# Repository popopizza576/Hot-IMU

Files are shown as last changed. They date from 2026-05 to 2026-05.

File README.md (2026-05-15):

# What is Hot IMU?
The Hot IMU is an IMU based camera tracker that attaches to any hot or cold shoe on a camera and captures its movement. This helps to create dynamic backgrounds using that movement data for compositing green screens instead of static images, which adds a whole new realm of possibilities to what you can do in video post-production and VFX!
### <a href="https://youtu.be/kCqcRCQPGMA">Watch the video here!</a>
github
ezgif-frame-

# Why use Hot IMU?
The Hot IMU is a great alternative to current Vive-tracker-based solutions for green screen compositing. The Hot IMU does not require any base stations or setup, just put it on and click go, and it will record your motion data.

The Hot IMU is also incredibly affordable compared to the current Vive-tracker-based solutions. It's also extremely affordable, not requiring base stations, which means you can use it virtually anywhere!

# Zine Page

hot IMU

# Assembly
The Hot IMU is a compact ESP-32c3-based device, with a BNO085 IMU and OLED screen. The IMU and OLED screen mount to the PCB with breadboard pins. The battery mounts using a JST 2-pin 1.5mm connector.

### PCB



### Schematic



### BOM

I have created two separate BOMs for my project, because some parts you can't order on Digikey. 

The first BOM plugs into Digikeys' lists and allows you to order things like SMD components for your board.

The second BOM is a list of all additional components you need to buy in order to complete the project.

**You need to buy the contents of BOTH BOMs to build this project!!!**

<a href="https://github.com/popopizza576/Hot-IMU/blob/main/BOM.csv">BOM1</a><br></br>
<a href="https://github.com/popopizza576/Hot-IMU/blob/main/BOM2.csv">BOM2</a>

**PLEASE NOTE**

In addition to purchasing the parts from the BOM, you must have access to a 3D Printer to print the shell for this project.

Also, note that you need to get a quote from a PCB manufacturer of your choosing. **YOU MUST PURCHASE A PCB** The PCB is not included in either BOM.

# Usage
The Hot IMU records movement data to the SD card in CSV format. It records one frame of motion data per frame, and the framerate is specified on the OLED screen.

You can change the framerate by holding down the GO button and pressing the STOP button. The built-in framerates are 24, 30, 60, and 120. the default framerate is 24.

After you've got your CSV file of the motion data recorded, you need to create a Blender scene and find the file path. There is a blender script you need to put in the Scripting tab in Blender.

The Blender Script will parse through the motion data and create an animation of the length of the duration of the data you recorded, then it creates 1 frame of animation for every frame and maps your camera movement to the motion capture.

After you render your Blender animation, just sync up your animation and footage from your camera in your editing software of choice, and key out the background!


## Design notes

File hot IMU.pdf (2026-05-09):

## Dynamic Composites using

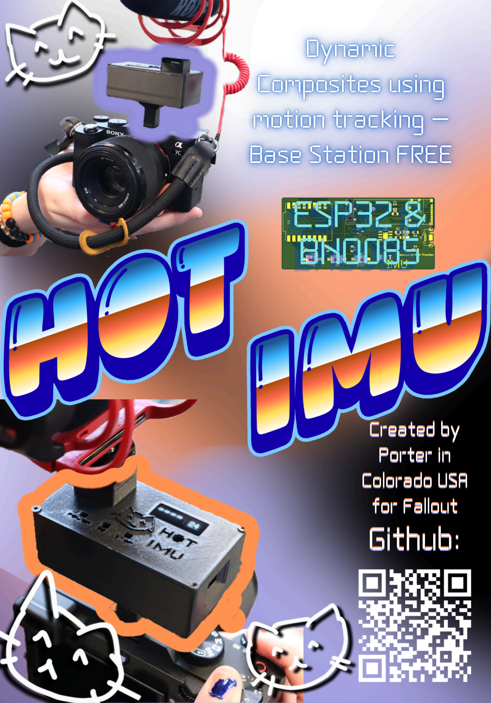
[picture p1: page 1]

## motion tracking -Base Station FREE

Created by
PPoorrtteerr i

inn
CCool

loorraaddoo UUSSAA
ffoorr FFaal

ll

loouutt

## GGiitthhuubb::

Created by
Porter in
Colorado USA
for Fallout

## Github:

# EEESSSPPP333222&&& BBBNNNOOO000888555

# ESP32 & BNO085

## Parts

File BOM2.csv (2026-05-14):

Part (Reference) | Qty | Link | Price
BNO085 | 1 | https://www.aliexpress.us/item/3256811467490032.html | $20.91
OLED 128×32 i2c | 1 | https://www.aliexpress.us/item/3256811597067737.html | $2.85
Self-tapping m2 screws | 1 | https://www.aliexpress.us/item/3256810220525698.html | $4.83
pin header (J4) | 1 | https://pmdway.com/products/single-row-smt-smd-female-header-socket-10-pack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 | $14.37
Battery (2 pin 1.5mm) | 1 | https://www.aliexpress.us/item/3256806334906334.html | $8.11

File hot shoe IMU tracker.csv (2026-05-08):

Reference | Qty | Value | DNP | Exclude from BOM | Exclude from Board | Footprint | Datasheet | MPN
BT1 | 1 | Battery |  |  |  | Connector_JST:JST_ACH_BM02B-ACHSS-GAN-ETF_1x02-1MP_P1.20mm_Vertical | ~ | B2B-ZR-SM4-TF
C1 | 1 | 0.1 |  |  |  | Capacitor_SMD:C_0402_1005Metric_Pad0.74x0.62mm_HandSolder | ~ | GRM155R71C104KA88D
C2 | 1 | 10 |  |  |  | Capacitor_SMD:C_0402_1005Metric_Pad0.74x0.62mm_HandSolder | ~ | GRM155R61A106ME11D
D1,D2 | 2 | LED |  |  |  | LED_SMD:LED_0805_2012Metric_Pad1.15x1.40mm_HandSolder | ~ | LTST-C170KRKT,LTST-C171KGKT
J1 | 1 | USB_B_Micro |  |  |  | Connector_USB:USB_Micro-AB_Molex_47590-0001 | ~ | 0475900001
J2 | 1 | Micro_SD_Card |  |  |  | Connector_Card:microSD_HC_Molex_104031-0811 | https://www.we-online.com/components/products/datasheet/693072010801.pdf | 1040310811
J3 | 1 | OLED |  |  |  | Connector_PinHeader_1.00mm:PinHeader_1x04_P1.00mm_Vertical_SMD_Pin1Left | ~ | SSM-104-L-SV-K-TR
J4 | 1 | BNO085 |  |  |  | Connector_PinHeader_1.27mm:PinHeader_1x10_P1.27mm_Vertical_SMD_Pin1Left | ~ | SSM-104-L-SV-K-TR
Q1 | 1 | 2N7002 |  |  |  | Package_TO_SOT_SMD:SOT-23 | https://www.onsemi.com/pub/Collateral/NDS7002A-D.PDF | 2N7002
R1,R2 | 2 | 1k |  |  |  | Resistor_SMD:R_0805_2012Metric_Pad1.20x1.40mm_HandSolder | ~ | CRCW08051K00FKEA
R3 | 1 | 0.4 |  |  |  | Resistor_SMD:R_0805_2012Metric_Pad1.20x1.40mm_HandSolder | ~ | RCWP0575400RGKS6
R4 | 1 | 1.2k |  |  |  | Resistor_SMD:R_0805_2012Metric_Pad1.20x1.40mm_HandSolder | ~ | CRCW08051K20FKEA
R5,R6,R7,R8 | 4 | 10k |  |  |  | Resistor_SMD:R_0805_2012Metric_Pad1.20x1.40mm_HandSolder | ~ | CRCW080510K0FKEA
SW1 | 1 | Power |  |  |  | Button_Switch_SMD:SW_DIP_SPSTx01_Slide_6.7x4.1mm_W8.61mm_P2.54mm_LowProfile | ~ | RS-282G05A3-SM RT
SW2 | 1 | Start |  |  |  | Button_Switch_SMD:SW_DIP_SPSTx01_Slide_6.7x4.1mm_W8.61mm_P2.54mm_LowProfile | ~ | RS-282G05A3-SM RT
SW3 | 1 | Stop |  |  |  | Button_Switch_SMD:SW_DIP_SPSTx01_Slide_6.7x4.1mm_W8.61mm_P2.54mm_LowProfile | ~ | RS-282G05A3-SM RT
U1 | 1 | ESP32-C3_SUPERMINI_TH |  |  |  | hot shoe:MODULE_ESP32-C3_SUPERMINI |  | 26892
U2 | 1 | TP4056-42-ESOP8 |  |  |  | Package_SO:SOIC-8-1EP_3.9x4.9mm_P1.27mm_EP2.41x3.3mm_ThermalVias | https://www.lcsc.com/datasheet/lcsc_datasheet_2410121619_TOPPOWER-Nanjing-Extension-Microelectronics-TP4056-42-ESOP8_C16581.pdf | TPB4056A20-ES1R

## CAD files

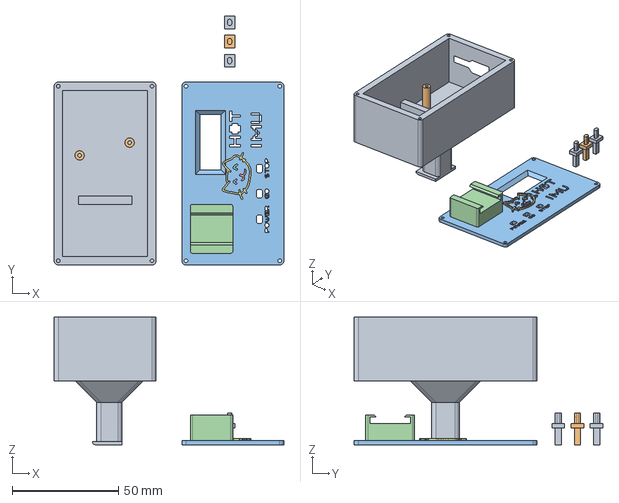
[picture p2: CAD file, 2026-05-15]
cad/body.step
108.0 x 117.0 x 60.0 mm

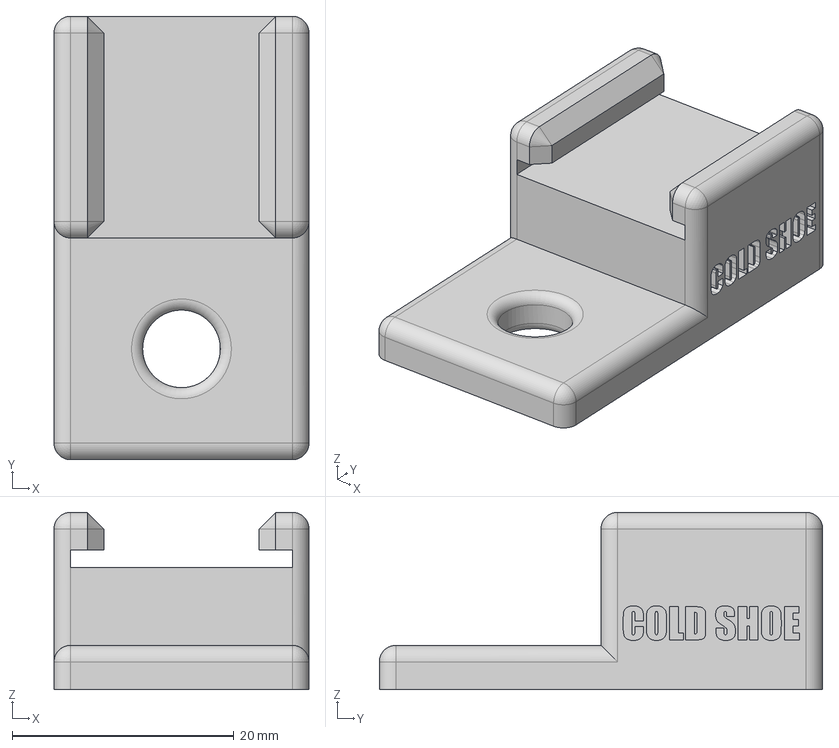
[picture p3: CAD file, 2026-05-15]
cad/m14-20 to cold shoe.step
23.0 x 40.0 x 16.0 mm

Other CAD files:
cad/body.f3d
cad/body.stl
cad/m14-20 to cold shoe.f3d
cad/m14-20 to cold shoe.stl

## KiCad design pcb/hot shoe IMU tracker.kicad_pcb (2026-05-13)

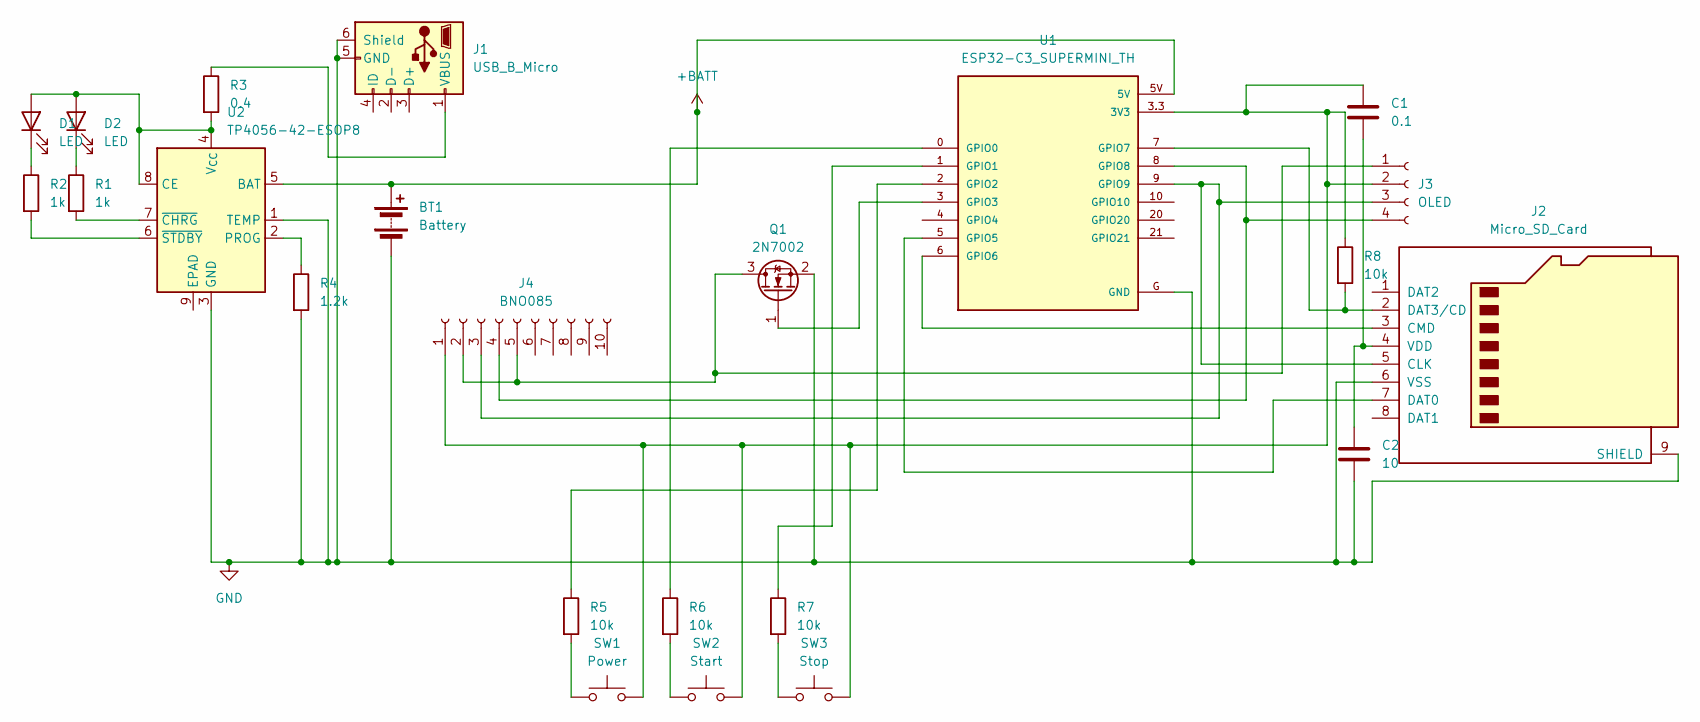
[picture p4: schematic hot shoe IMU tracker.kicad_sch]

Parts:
BT1: Battery; JST_ACH_BM02B-ACHSS-GAN-ETF_1x02-1MP_P1.20mm_Vertical; MPN B2B-ZR-SM4-TF
C1: 0.1; C_0402_1005Metric_Pad0.74x0.62mm_HandSolder; MPN GRM155R71C104KA88D
C2: 10; C_0402_1005Metric_Pad0.74x0.62mm_HandSolder; MPN GRM155R61A106ME11D
D1: LED; LED_0805_2012Metric_Pad1.15x1.40mm_HandSolder; MPN LTST-C171KGKT
D2: LED; LED_0805_2012Metric_Pad1.15x1.40mm_HandSolder; MPN LTST-C170KRKT
J1: USB_B_Micro; USB_Micro-AB_Molex_47590-0001; MPN 0475900001
J2: Micro_SD_Card; microSD_HC_Molex_104031-0811; MPN 1040310811
J3: OLED; PinHeader_1x04_P1.00mm_Vertical_SMD_Pin1Left; MPN SSM-104-L-SV-K-TR
J4: BNO085; PinHeader_1x10_P1.27mm_Vertical_SMD_Pin1Left; MPN SSM-104-L-SV-K-TR
Q1: 2N7002; SOT-23; MPN 2N7002
R1, R2: 1k; R_0805_2012Metric_Pad1.20x1.40mm_HandSolder; MPN CRCW08051K00FKEA
R3: 0.4; R_0805_2012Metric_Pad1.20x1.40mm_HandSolder; MPN RCWP0575400RGKS6
R4: 1.2k; R_0805_2012Metric_Pad1.20x1.40mm_HandSolder; MPN CRCW08051K20FKEA
R5, R6, R7, R8: 10k; R_0805_2012Metric_Pad1.20x1.40mm_HandSolder; MPN CRCW080510K0FKEA
SW1: Power; SW_DIP_SPSTx01_Slide_6.7x4.1mm_W8.61mm_P2.54mm_LowProfile; MPN RS-282G05A3-SM RT
SW2: Start; SW_DIP_SPSTx01_Slide_6.7x4.1mm_W8.61mm_P2.54mm_LowProfile; MPN RS-282G05A3-SM RT
SW3: Stop; SW_DIP_SPSTx01_Slide_6.7x4.1mm_W8.61mm_P2.54mm_LowProfile; MPN RS-282G05A3-SM RT
U1: ESP32-C3_SUPERMINI_TH; MODULE_ESP32-C3_SUPERMINI; MPN 26892
U2: TP4056-42-ESOP8; SOIC-8-1EP_3.9x4.9mm_P1.27mm_EP2.41x3.3mm_ThermalVias; MPN TPB4056A20-ES1R

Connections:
+BATT: BT1.1 (+), U1.5V, U2.5 (BAT)
GND: BT1.2 (-), C2.2, J1.5 (GND), J1.6 (Shield), J2.6 (VSS), J2.9 (SHIELD), Q1.2 (S), R4.2, U1.G (GND), U2.1 (TEMP), U2.3 (GND)
unnamed: D1.2 (A), D2.2 (A), R3.2, U2.4 (V_{CC}), U2.8 (CE)
unnamed: D1.1 (K), R2.1
unnamed: D2.1 (K), R1.1
unnamed: J1.1 (VBUS), R3.1
unnamed: J2.5 (CLK), J3.3, J4.3, U1.9 (GPIO9)
unnamed: J2.3 (CMD), U1.6 (GPIO6)
unnamed: J2.7 (DAT0), U1.5 (GPIO5)
unnamed: J2.2 (DAT3/CD), R8.2, U1.7 (GPIO7)
unnamed: C1.2, C2.1, J2.4 (VDD)
unnamed: J3.1, J4.2, J4.5, Q1.3 (D)
unnamed: C1.1, J3.2, J4.1, R8.1, SW1.2, SW2.2, SW3.2, U1.3.3 (3V3)
unnamed: J3.4, J4.4, U1.8 (GPIO8)
unnamed: Q1.1 (G), U1.3 (GPIO3)
unnamed: R5.2, SW1.1
unnamed: R6.2, SW2.1
unnamed: R7.2, SW3.1
unnamed: R6.1, U1.0 (GPIO0)
unnamed: R7.1, U1.1 (GPIO1)
unnamed: R5.1, U1.2 (GPIO2)
unnamed: R4.1, U2.2 (PROG)
unnamed: R1.2, U2.7 (~CHRG)
unnamed: R2.2, U2.6 (~STDBY)

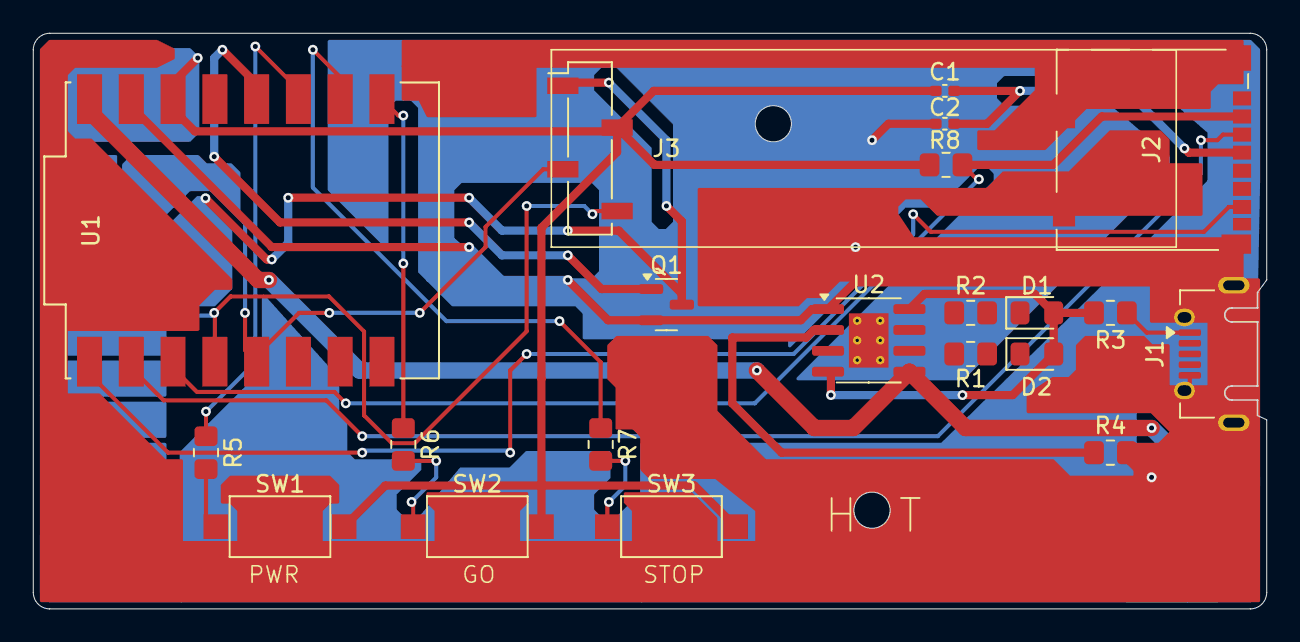
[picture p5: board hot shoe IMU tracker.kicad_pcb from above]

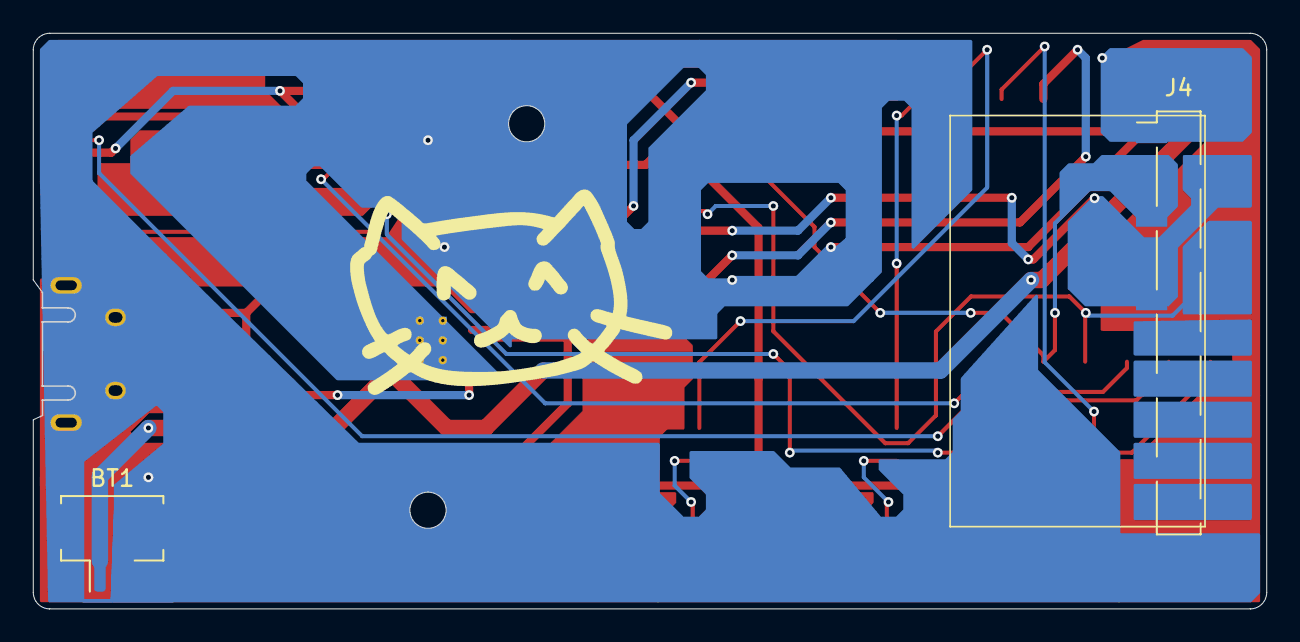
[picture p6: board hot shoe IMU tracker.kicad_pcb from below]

Board: 2 copper layers, 75.0 x 35.0 mm, 23 parts (2 on the bottom side), 24 nets.

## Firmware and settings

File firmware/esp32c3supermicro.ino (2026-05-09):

#include <Wire.h>
#include <Adafruit_GFX.h>
#include <Adafruit_SSD1306.h>
#include <Adafruit_MPU6050.h>
#include <Adafruit_Sensor.h>
#include <Adafruit_BNO08x.h>
//something for sleep mode i think
#include "driver/rtc_io.h"
#include "esp_sleep.h"
//file system
#include "FS.h"
//sd card
#include "SD.h"
//serial
#include "SPI.h"
//does something with the BNO085 (i dont know i just work here)
#define BNO08X_RESET -1

//defines the motion tracker
Adafruit_MPU6050 mpu;
Adafruit_BNO08x  bno08x(BNO08X_RESET);
sh2_SensorValue_t sensorValue;

//defines file (test)
File currentFile;

// Define OLED screen size
#define SCREEN_WIDTH 128
#define SCREEN_HEIGHT 32
#define SD_MOSI     6
#define SD_MISO     5
#define SD_SCLK     4
#define SD_CS       7
#define WAKEUP_GPIO GPIO_NUM_2

// Initialize OLED display (I2C address 0x3C)
Adafruit_SSD1306 display(SCREEN_WIDTH, SCREEN_HEIGHT, &Wire, -1);

// define variables yo
int hoursTC = 00;
int minutesTC = 00;
int secondsTC = 00;
int framesTC = 00;
String fullTimeCodeString = "placeholder";
int framerateSelector = 0;
int commonFramerates[] = {24, 30, 60, 120};
int framerate = commonFramerates[framerateSelector];
int frameDelay = 1000 / framerate;
unsigned long msTimeTrack;
int frameTrackInt = frameDelay;
int secTrackInt = 1000;
int startButtonState = 0;
int startButtonPin = 0;
int stopButtonState = 0;
int stopButtonPin = 1;
int powerButtonPin = 2;
int powerButtonState = 0;
int powerRailPin = 3;
int timecodeRunning = 0;
int recordDisplay = 0;
int recBlinkMs = 0;
int frameTotal = 0;
int gravityConst = 0;
int normalScreen = true;
float gyroXOffset = 0;
float gyroYOffset = 0;
float gyroZOffset = 0;
float xAcceleration = 0;
float yAcceleration = 0;
float zAcceleration = 0;
float xGyro = 0;
float yGyro = 0;
float zGyro = 0;
int foundFile = 0;
int lazyCounter = 0;
int frameCorrectionInteger = 0;
unsigned long msSinceOn = 0;
unsigned long elapsed = 0;
String csvString;

void setup() {
    //stuff for the power rail, because it has a power button
    pinMode(powerRailPin, OUTPUT);
    digitalWrite(powerRailPin, HIGH);

    //serial console stuff
    Serial.begin(115200);
    delay(1000);
    Serial.println("Booted");

    //more stuff for the power button feature
      esp_deep_sleep_enable_gpio_wakeup(1 << WAKEUP_GPIO, ESP_GPIO_WAKEUP_GPIO_HIGH);



    //set pin modes
    pinMode(startButtonPin, INPUT);
    pinMode(stopButtonPin, INPUT);

    //define stuff
    gravityConst = 11;

    // combine TC values
    fullTimeCodeString = hoursTC + ":"; 
    fullTimeCodeString = fullTimeCodeString + minutesTC;
    fullTimeCodeString = fullTimeCodeString + ":";
    fullTimeCodeString = fullTimeCodeString + secondsTC;
    fullTimeCodeString = fullTimeCodeString + ":"; 
    fullTimeCodeString = fullTimeCodeString + framesTC;
    
    // Start OLED display
    if (!display.begin(SSD1306_SWITCHCAPVCC, 0x3C)) {
        Serial.println("SSD1306 allocation failed");
        for (;;);
    }
  //SD card mounting and stuff
  SPI.begin(SD_SCLK, SD_MISO, SD_MOSI, SD_CS);
  if (!SD.begin(SD_CS)) 
  {
    Serial.println("SD Card MOUNT FAIL");
  } 
  





    //THIS STUFF IS FROM WHEN I HAD AN MPU6050 AS A MOTION TRACKER --  DO NOT USE

    //initialize motion tracker
    //if (!mpu.begin()) {
    //Serial.println("Failed to find MPU6050 chip");
    //while (1) {
    //  delay(10);
    //}
  ///}
  //Serial.println("MPU6050 Found!");


  if (!bno08x.begin_I2C()) { // Start the sensor using I2C
    Serial.println("Failed to find BNO08x chip");
    while (1) { delay(10); }
  }
  Serial.println("BNO08x Found!");

  setReports();

  // set accelerometer range to +-8G -- MPU6050 doesnt matter
  //mpu.setAccelerometerRange(MPU6050_RANGE_8_G);

  // set gyro range to +- 500 deg/s -- MPU6050 doesnt matter
  //mpu.setGyroRange(MPU6050_RANGE_2000_DEG);

  // set filter bandwidth to 21 Hz -- MPU6050 doesnt matter
  //mpu.setFilterBandwidth(MPU6050_BAND_5_HZ);

  //updates the OLED display
  delay(100);

    display.clearDisplay();  // Clear buffer
    display.setTextSize(2);  // Text size
    display.setTextColor(SSD1306_WHITE);
    display.setCursor(10, 10);
    display.println(fullTimeCodeString);
    display.display(); // Show text on screen

    //drawing the framerate display
    display.clearDisplay();  // Clear buffer
    display.setTextSize(2);  // Text size
    display.setTextColor(SSD1306_WHITE);
    display.setCursor(80, 10);
    display.println(framerate);
    display.display(); // Show text on screen
}

//stuff for BNO085 (good :>)
void setReports(void) {
  Serial.println("Setting desired reports");

   if (!bno08x.enableReport(SH2_LINEAR_ACCELERATION, 10000)) {
    Serial.println("Could not enable linear accel");
  }

  if (!bno08x.enableReport(SH2_GYROSCOPE_CALIBRATED, 10000)) {
    Serial.println("Could not enable gyro");
  }
}



void loop() {

    //declaring stuff
    msTimeTrack = millis();
    elapsed = msTimeTrack - msSinceOn;
    startButtonState = digitalRead(startButtonPin);
    stopButtonState = digitalRead(stopButtonPin);
    powerButtonState = digitalRead(powerButtonPin);

    

    //buttons
    if (startButtonState == HIGH) {
      while (true) {

      startButtonState = digitalRead(startButtonPin);
      stopButtonState = digitalRead(stopButtonPin);


        if (startButtonState == LOW) {
          msSinceOn = msTimeTrack;
          elapsed = msTimeTrack - msSinceOn;
          secTrackInt = elapsed;
          timecodeRunning = true;
          Serial.println(msSinceOn);
          findFileName();
          break;
        }

        if(stopButtonState == HIGH) {
          //framerate change

          delay(100);

          if (framerateSelector >= 3) {
            framerateSelector = 0;
          } else {
            framerateSelector++;
          }
          framerate = commonFramerates[framerateSelector];
          break;

        }
      }


    }

    if (stopButtonState == HIGH) {
      timecodeRunning = false;
      framesTC = 0;
      secondsTC = 0;
      minutesTC = 0;
      hoursTC = 0;
      frameTotal = 0;
      frameTrackInt = frameDelay;
      frameCorrectionInteger = 0;
      currentFile.close();
      foundFile = false;
    }



    if (timecodeRunning == true) {
      updateTimeCodeLogic();
      recordDisplayLogic();
    } else {
      recordDisplay = false;
    }


    //Just updates the timecode string using the update timecode function
    updateTimeCodeString();

    //updates the motion tracking variables for the mpu6050 (i wanna switch to bno085)
    //mpu6050Update();
    bno085Update();
    
    if (powerButtonState == true) {
      digitalWrite(powerRailPin, LOW);
      delay(500);
      esp_deep_sleep_start();


    }

    // updating the display stuff

    if (normalScreen == true) {
      updateScreen();
    }
    


}

//does the thing that says "Recording" and blinks on the screen
void recordDisplayLogic() {
    if (msTimeTrack - recBlinkMs >= 1000) {
      recBlinkMs = msTimeTrack;
      if (recordDisplay == true) {
        recordDisplay = false;
      } else if (recordDisplay == false) {
        recordDisplay = true;
      }
    } 

}

//updates timecode values as time goes on
void updateTimeCodeLogic() {
    //uses millis as a reference for frames (but it do a lotta rounding cuz integers)

    if (framesTC < framerate) {
      
      if (elapsed >= frameTrackInt) {
      framesTC++;
      frameTotal++;

      if (framesTC < framerate) {
        frameTrackInt = frameTrackInt + frameDelay;
      }

      if (frameCorrectionInteger < framerate - 1) {
        frameCorrectionInteger++;
      } else {
        frameCorrectionInteger = 0;
        frameTrackInt = frameTrackInt + (1000 % framerate);
        Serial.println(frameTrackInt);
        Serial.println(elapsed);
      }

      //prints motion data to console
      printMotionData();
      Serial.println(fullTimeCodeString);
      }
      
    } else if (framesTC == framerate && elapsed >= frameTrackInt && frameCorrectionInteger == 0) {
      framesTC = 0;
    }


    //links seconds to millis, I think this would be more accurate
    if (elapsed - secTrackInt >= 1000) {
      secTrackInt += 1000;
      secondsTC++;
      frameTrackInt = frameTrackInt + frameDelay;
      //Serial.println(secondsTC);
        if (secondsTC == 60) {
          secondsTC = 0;
          minutesTC++;
      }
    } 
    
    //my other if statement :p
    if (minutesTC == 60) {
      minutesTC = 0;
      hoursTC++;
    }
    

}

//updates the timecode string from the timecode values
void updateTimeCodeString() {
    //updates timecode stuff

    //hours updates
    if (hoursTC < 1) {
      fullTimeCodeString = "00:";
    } else if (hoursTC < 10) {
      fullTimeCodeString = "0" + hoursTC;
      fullTimeCodeString = hoursTC + ":";
    } else {
      fullTimeCodeString = hoursTC + ":";
    }

    //minutes updates
    if (minutesTC < 10) {
      fullTimeCodeString = fullTimeCodeString + "0";
      fullTimeCodeString = fullTimeCodeString + minutesTC;
      fullTimeCodeString = fullTimeCodeString + ":";
    } else {
      fullTimeCodeString = fullTimeCodeString + minutesTC;
      fullTimeCodeString = fullTimeCodeString + ":";
    }

    //seconds updates
    if (secondsTC < 10) {
      fullTimeCodeString = fullTimeCodeString + "0";
      fullTimeCodeString = fullTimeCodeString + secondsTC;
      fullTimeCodeString = fullTimeCodeString + ":";
    } else {
      fullTimeCodeString = fullTimeCodeString + secondsTC;
      fullTimeCodeString = fullTimeCodeString + ":";
    }

    //frames updates

    if (framesTC < 10) {
      fullTimeCodeString = fullTimeCodeString + "0";
      fullTimeCodeString = fullTimeCodeString + framesTC;
    } else {
      fullTimeCodeString = fullTimeCodeString + framesTC;
    }


}

//mpu6050 doesnt matter blehhhh
void mpu6050Update() {
  sensors_event_t a, g, temp;
  mpu.getEvent(&a, &g, &temp);
  xAcceleration = a.acceleration.x;
  yAcceleration = a.acceleration.y;
  zAcceleration = a.acceleration.z;
  xGyro = g.gyro.x;
  yGyro = g.gyro.y;
  zGyro = g.gyro.z;
}

//bno085 does matter! :D
void bno085Update() {

  if (bno08x.wasReset()) {
    Serial.println("sensor reset");
    setReports();
  }

  while (bno08x.getSensorEvent(&sensorValue)) {

    switch (sensorValue.sensorId) {

      case SH2_LINEAR_ACCELERATION:
        xAcceleration = sensorValue.un.linearAcceleration.x;
        yAcceleration = sensorValue.un.linearAcceleration.y;
        zAcceleration = sensorValue.un.linearAcceleration.z;
        break;

      case SH2_GYROSCOPE_CALIBRATED:
        xGyro = sensorValue.un.gyroscope.x;
        yGyro = sensorValue.un.gyroscope.y;
        zGyro = sensorValue.un.gyroscope.z;
        break;

    }
  }


}

//updates the motion data to the SD card
void printMotionData() {


  csvString = String(xAcceleration) + "," + String(yAcceleration) + "," + String(zAcceleration) + "," + String((xGyro - gyroXOffset)) + "," + String((yGyro - gyroYOffset)) + "," + String((zGyro - gyroZOffset));
  currentFile.println(csvString);
  Serial.println("logged motion data");
  
}

//updates the OLED
void updateScreen() {
  // updating the display stuff
  display.clearDisplay();  // Clear buffer
  display.setTextSize(1.5);  // Text size
  display.setTextColor(SSD1306_WHITE);
  display.setCursor(10, 8);
  display.println(fullTimeCodeString);
  display.setTextSize(2);
  display.setCursor(100, 10);
  display.println(framerate);
  if (recordDisplay == true) {
    display.setTextSize(1);
    display.setCursor(10, 22);
    display.println("Recording");
  }
    
  display.display(); // Show text on screen
}

void calibrateGyro(){
  Serial.println("Calibrating the Gyro: Keep Completely Stationary");
  display.clearDisplay();  // Clear buffer
  display.setTextSize(1);  // Text size
  display.setTextColor(SSD1306_WHITE);
  display.setCursor(10, 10);
  display.println("Calibrating in: 3");
  display.display();
  delay(1000);
  display.clearDisplay();  // Clear buffer
  display.setTextSize(1);  // Text size
  display.setTextColor(SSD1306_WHITE);
  display.setCursor(10, 10);
  display.println("Calibrating in: 2");
  display.display();
  delay(1000);
  display.clearDisplay();  // Clear buffer
  display.setTextSize(1);  // Text size
  display.setTextColor(SSD1306_WHITE);
  display.setCursor(10, 10);
  display.println("Calibrating in: 1");
  display.display();
  delay(1000);
  display.clearDisplay();  // Clear buffer
  display.setTextSize(1);  // Text size
  display.setTextColor(SSD1306_WHITE);
  display.setCursor(10, 10);
  display.println("Calibrating, please wait...");
  display.display();
  int i;
  float sumX = 0;
  float sumY = 0;
  float sumZ = 0;
  int numPoints=1000;
  for (i=0;i<numPoints;i=i+1){
    sensors_event_t a, g, temp;
    mpu.getEvent(&a, &g, &temp);
    sumX = sumX + g.gyro.x;
    sumY = sumY + g.gyro.y;
    sumZ = sumZ + g.gyro.z;
    delay(10);
}
gyroXOffset = sumX/numPoints;
gyroYOffset = sumY/numPoints;
gyroZOffset = sumZ/numPoints;

normalScreen = true;
}

//makes sure that files have new names in the SD card
void findFileName () {
  lazyCounter = 0;
  while (true) {
    String filename = "/" + String(lazyCounter) + ".csv";

    if (!SD.exists(filename)) {
      currentFile = SD.open(filename, FILE_WRITE);
      break;           
    }

    lazyCounter++;
  }

  }
